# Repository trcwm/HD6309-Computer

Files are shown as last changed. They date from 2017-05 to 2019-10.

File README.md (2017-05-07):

# HD6309-Computer
A computer based on the HD6309 CPU, done for the Retro Challenge 2017/04.

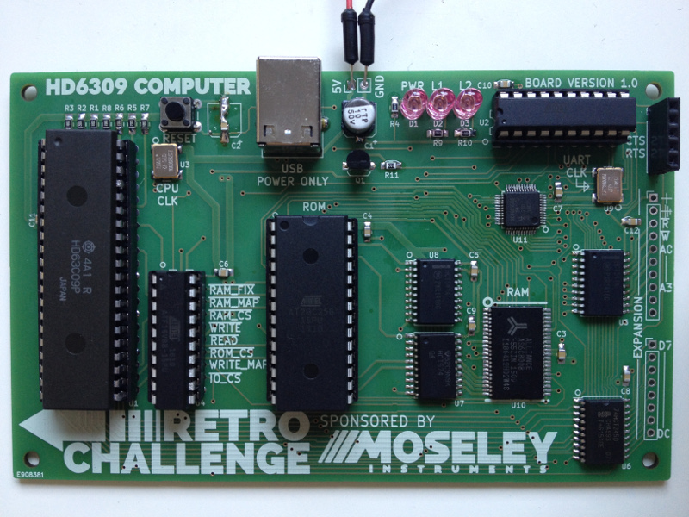
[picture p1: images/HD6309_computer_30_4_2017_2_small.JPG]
HD6309 Computer Image

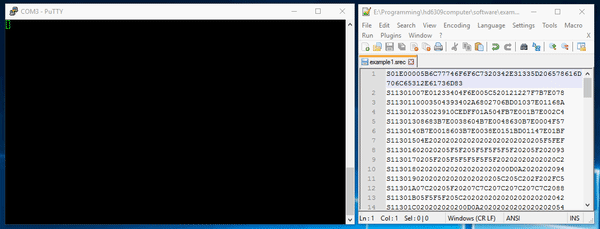
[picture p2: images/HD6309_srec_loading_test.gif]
HD6309 Computer Image


Read the blog: [https://namoseley.wordpress.com/category/retrochallenge/](https://namoseley.wordpress.com/category/retrochallenge/)

Features:
* HD6309 CPU
	* Binary compatible to MC6809
	* ..but faster instruction execution,
	* ..extended registers,
	* ..additional instructions,
	* and lots more!
* 1MB of RAM:
    * mapped in 32K pages at 0x0000 .. 0x7FFF
    * fixed page at 0x8000 .. 0xDFFF
* 2KB of IO space:
    * SC16C550B UART at 0xE000
    * 8-bit expansions port at 0xE010(untested!)
* Memory map register:
    * 5-bit entry sets A15..A19 on RAM
    * reg at address 0xE800
* 4KB of ROM:
    * Memory check
    * SREC loader

Licence: CERN Open Hardware Licence v1.2

Development time provided by: http://www.moseleyinstruments.com

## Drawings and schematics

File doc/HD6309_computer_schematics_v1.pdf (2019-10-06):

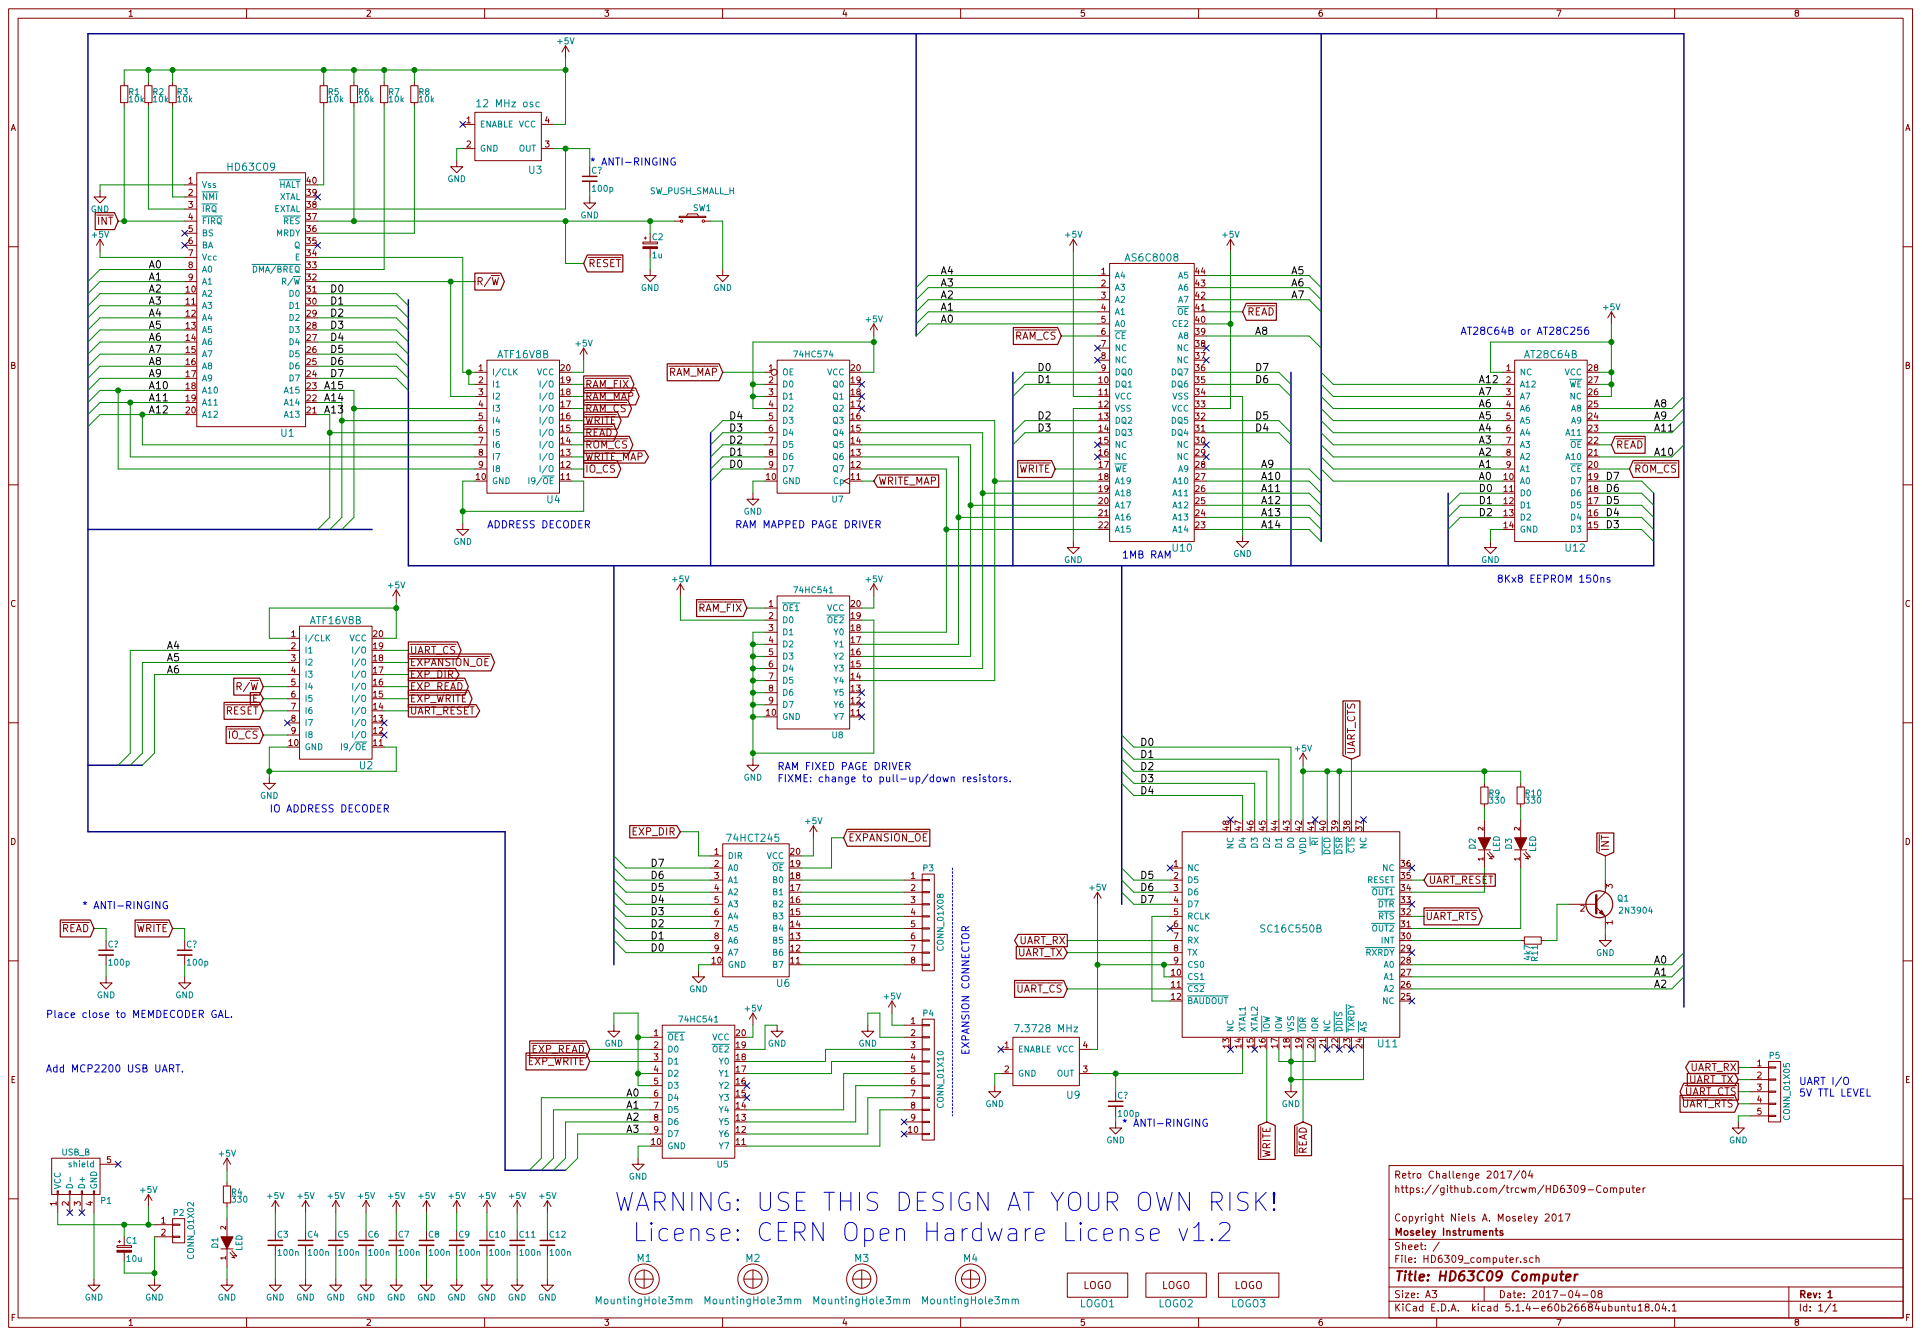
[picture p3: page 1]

I4 5
I5 6

5V TTL LEVEL RAM FIXED PAGE DRIVER
FIXME: change to pull-up/down resistors.

Place close to MEMDECODER GAL.

WARNING: USE THIS DESIGN AT YOUR OWN RISK!
License: CERN Open Hardware License v1.2

https://github.com/trcwm/HD6309-Computer

Copyright Niels A. Moseley 2017
File: HD6309_computer.sch Sheet: / Moseley Instruments

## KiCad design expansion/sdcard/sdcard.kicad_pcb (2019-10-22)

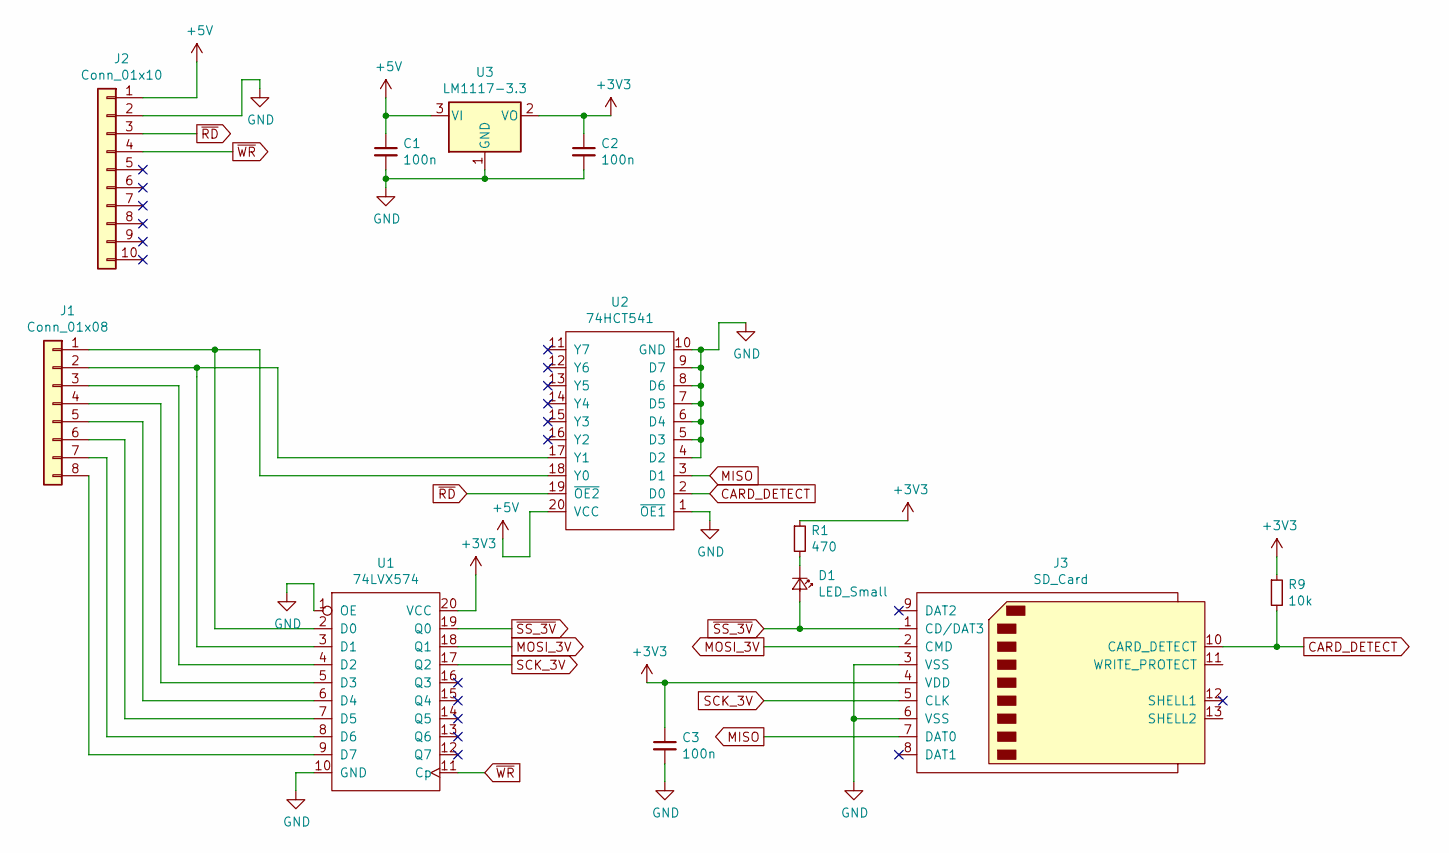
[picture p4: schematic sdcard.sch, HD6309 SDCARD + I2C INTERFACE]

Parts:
C1, C2, C3: 100n; C_0805_2012Metric_Pad1.15x1.40mm_HandSolder
D1: LED_Small; LED_0805_2012Metric_Pad1.15x1.40mm_HandSolder
J1: Conn_01x08; PinHeader_1x08_P2.54mm_Vertical
J2: Conn_01x10; PinHeader_1x10_P2.54mm_Vertical
J3: SD_Card; SD_TE_2041021
R1: 470; R_0805_2012Metric_Pad1.15x1.40mm_HandSolder
R9: 10k; R_0805_2012Metric_Pad1.15x1.40mm_HandSolder
U1: 74LVX574; SOIC-20W_7.5x12.8mm_P1.27mm
U2: 74HCT541; SOIC-20W_7.5x12.8mm_P1.27mm
U3: LM1117-3.3; SOT-223-3_TabPin2

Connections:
+3V3: C2.1, C3.1, J3.4 (VDD), R1.1, R9.1, U1.20 (VCC), U3.2 (VO)
+5V: C1.1, J2.1, U2.20 (VCC), U3.3 (VI)
CARD_DETECT: J3.10 (CARD_DETECT), R9.2, U2.2 (D0)
GND: C1.2, C2.2, C3.2, J2.2, J3.3 (VSS), J3.6 (VSS), U1.1 (OE), U1.10 (GND), U2.1 (~OE1), U2.4 (D2), U2.5 (D3), U2.6 (D4), U2.7 (D5), U2.8 (D6), U2.9 (D7), U2.10 (GND), U3.1 (GND)
MISO: J3.7 (DAT0), U2.3 (D1)
MOSI_3V: J3.2 (CMD), U1.18 (Q1)
unnamed: D1.1 (K), R1.2
unnamed: J1.1, U1.2 (D0), U2.18 (Y0)
unnamed: J1.2, U1.3 (D1), U2.17 (Y1)
unnamed: J1.3, U1.4 (D2)
unnamed: J1.4, U1.5 (D3)
unnamed: J1.5, U1.6 (D4)
unnamed: J1.6, U1.7 (D5)
unnamed: J1.7, U1.8 (D6)
unnamed: J1.8, U1.9 (D7)
SCK_3V: J3.5 (CLK), U1.17 (Q2)
~RD: J2.3, U2.19 (~OE2)
~SS_3V: D1.2 (A), J3.1 (CD/DAT3), U1.19 (Q0)
~WR: J2.4, U1.11 (Cp)

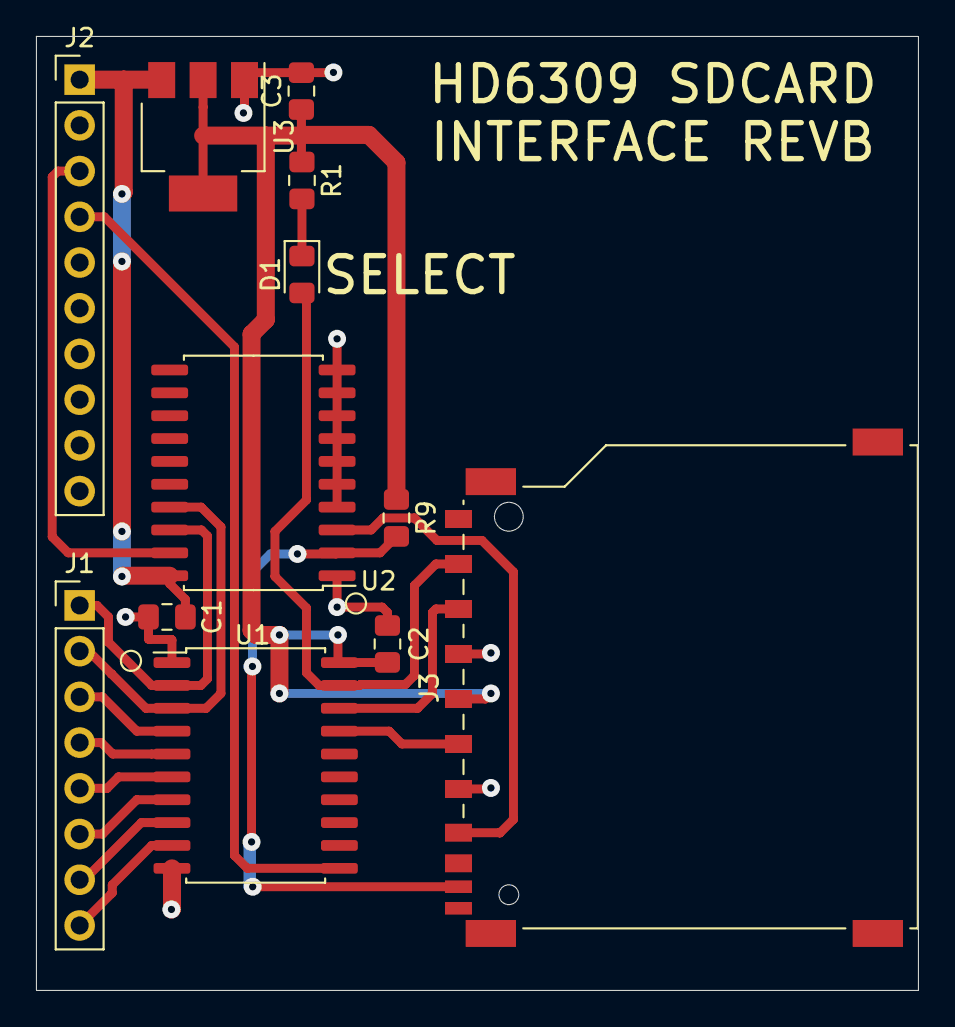
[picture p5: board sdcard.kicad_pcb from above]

Board: 2 copper layers, 49.0 x 53.0 mm, 12 parts (0 on the bottom side), 19 nets.

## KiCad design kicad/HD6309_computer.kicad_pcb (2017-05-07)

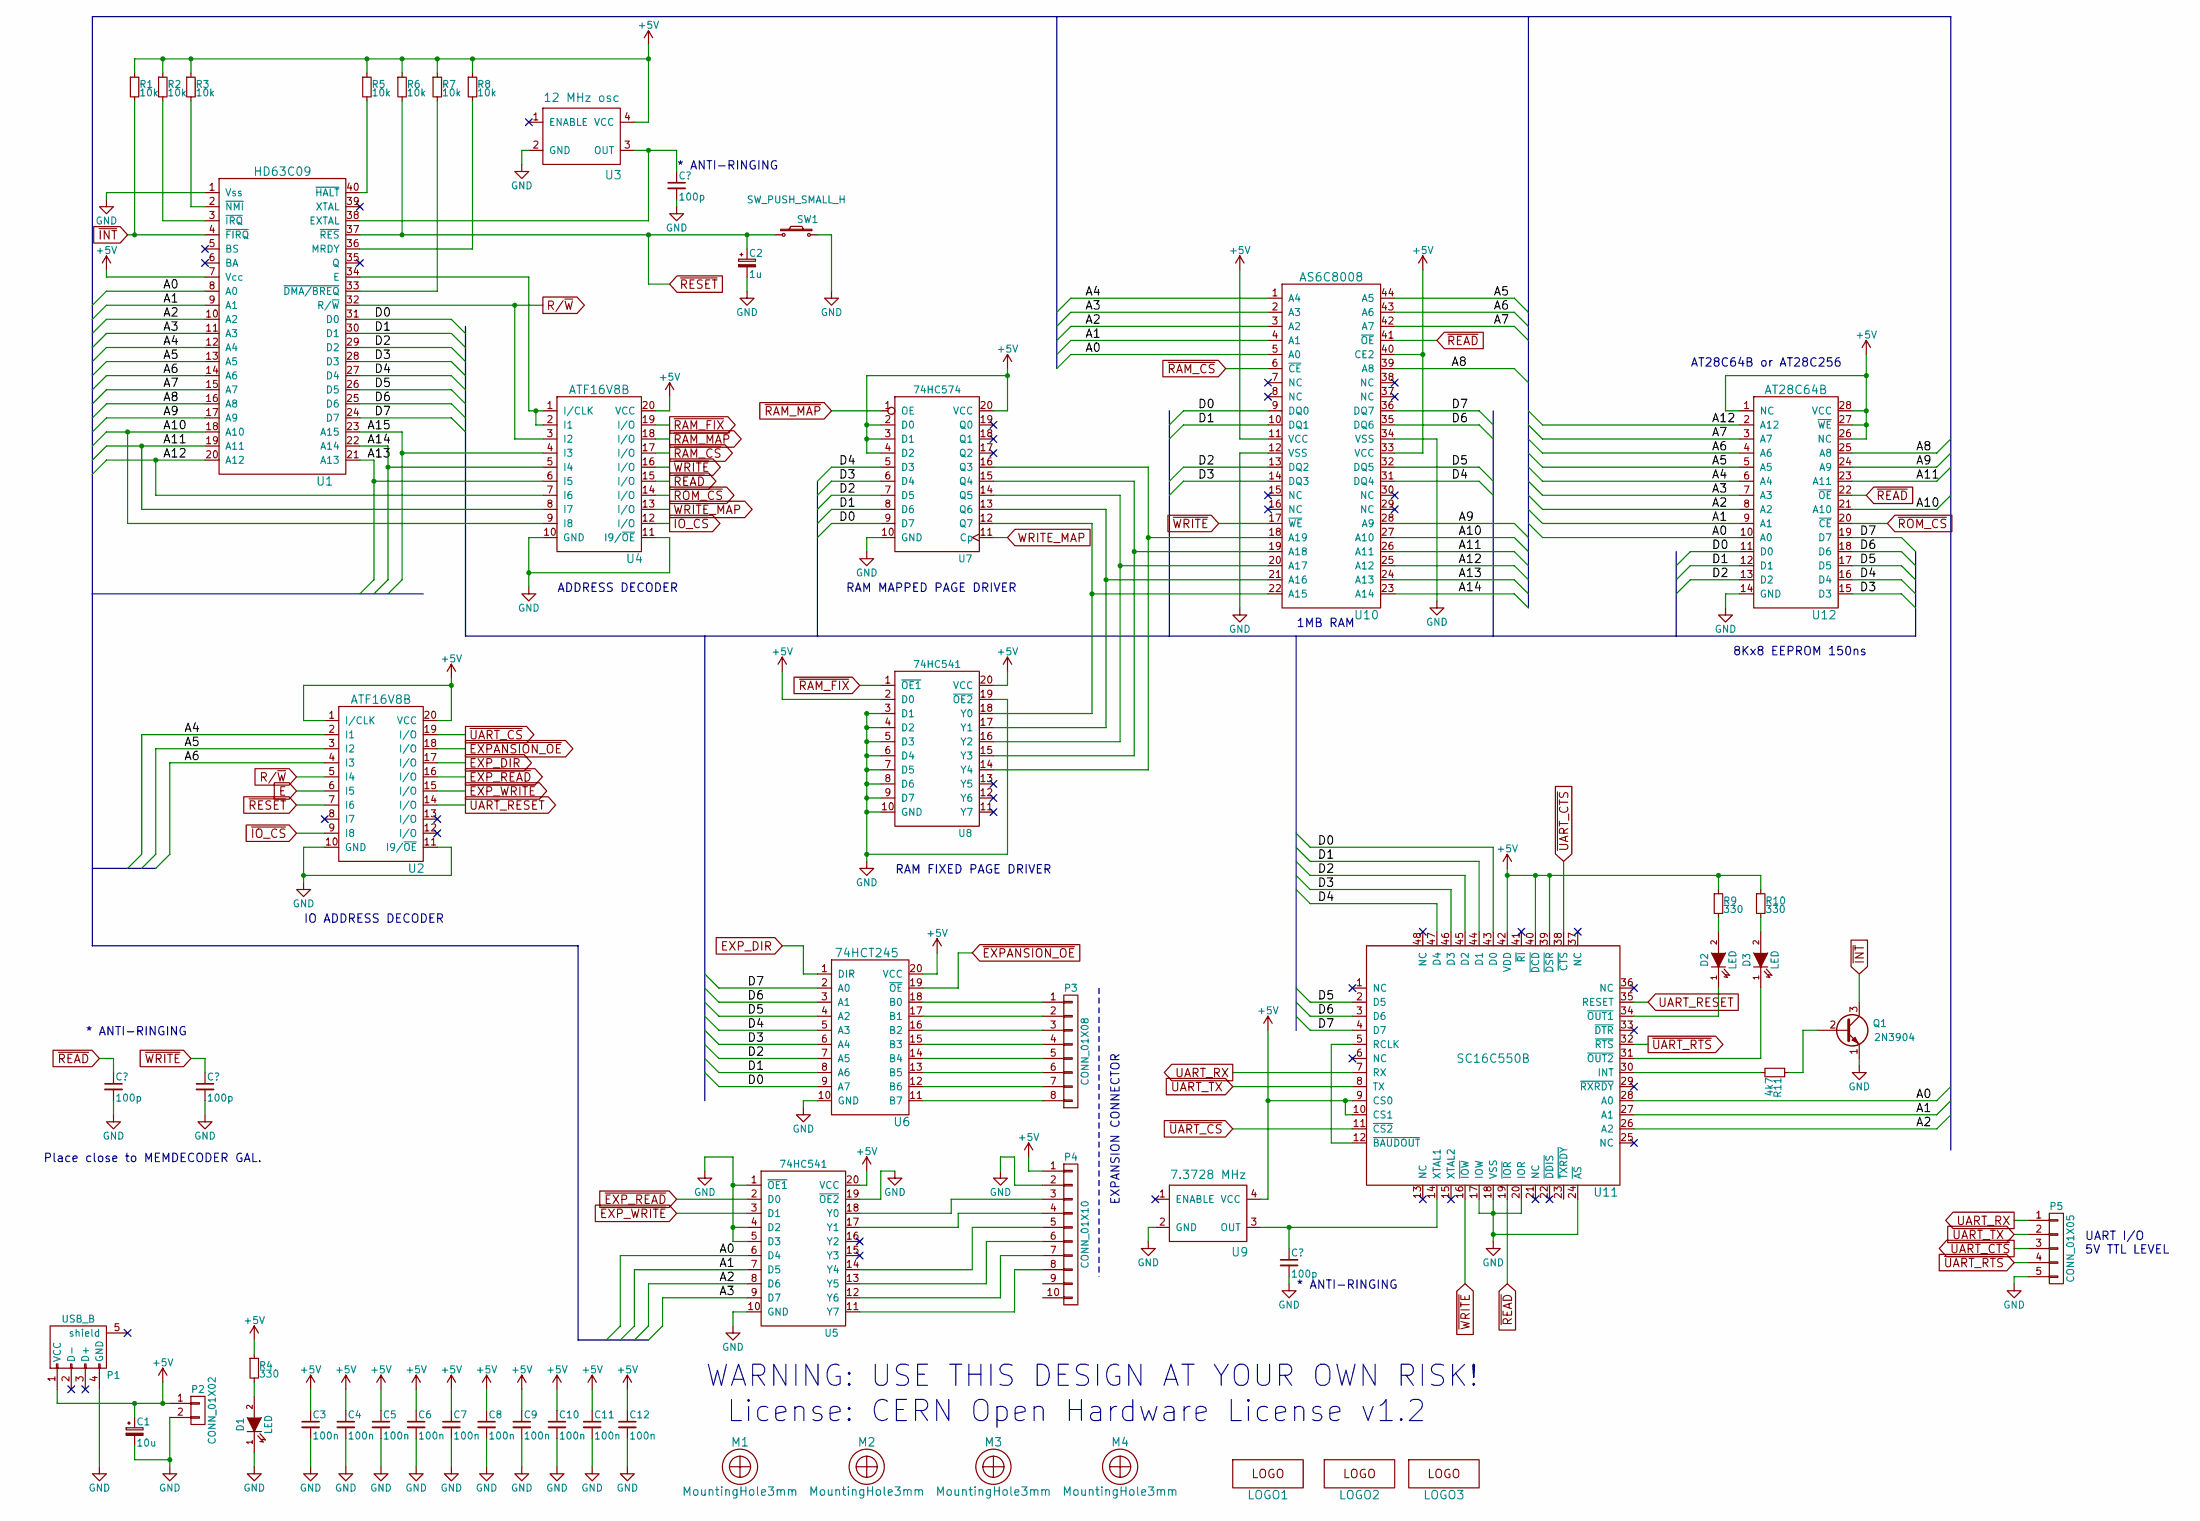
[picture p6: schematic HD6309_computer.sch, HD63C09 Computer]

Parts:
C1: 10u; CP_Elec_6.3x5.3
C2: 1u; CP_Elec_6.3x5.3
C3, C4, C5, C6, C7, C8, C9, C10, C11, C12: 100n; C_0805_HandSoldering
D1, D2, D3: LED; LED_D3.0mm_centered
LOGO1: Logo; moseley_instruments_logo_smaller
LOGO2: Logo; retro_challenge_logo
LOGO3: Logo; HD6309_computer_name
M1, M2, M3, M4: MountingHole3mm; MountingHole_3.2mm_M3_DIN965
P1: USB_B
P2: CONN_01X02; Pin_Header_Straight_1x02_Pitch2.54mm
P3: CONN_01X08; Pin_Header_Straight_1x08_Pitch2.54mm
P4: CONN_01X10; Pin_Header_Straight_1x10_Pitch2.54mm
P5: CONN_01X05; Pin_Header_Straight_1x05_Pitch2.54mm
Q1: 2N3904; TO-92_Inline_Wide
R1, R2, R3, R5, R6, R7, R8: 10k; R_0805_HandSoldering
R4, R9, R10: 330; R_0805_HandSoldering
R11: 4k7; R_0805_HandSoldering
SW1: SW_PUSH_SMALL_H; SW_PUSH_6mm
U1: HD63C09; DIP-40_W15.24mm_LongPads
U2, U4: ATF16V8B; DIP-20_W7.62mm_LongPads
U3: 12 MHz osc; OSCSMD7x5
U5, U8: 74HC541; SOIC-20W_7.5x12.8mm_Pitch1.27mm
U6: 74HCT245; SOIC-20W_7.5x12.8mm_Pitch1.27mm
U7: 74HC574; SOIC-20W_7.5x12.8mm_Pitch1.27mm
U9: 7.3728 MHz; OSCSMD7x5
U10: AS6C8008; TSOP-II_44pin_W400mil
U11: SC16C550B; LQFP-48_7x7mm_Pitch0.5mm
U12: AT28C64B; DIP-28_W15.24mm_LongPads

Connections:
/A0: U1.8 (A0), U5.6 (D4), U10.5 (A0), U11.28 (A0), U12.10 (A0)
/A1: U1.9 (A1), U5.7 (D5), U10.4 (A1), U11.27 (A1), U12.9 (A1)
/A2: U1.10 (A2), U5.8 (D6), U10.3 (A2), U11.26 (A2), U12.8 (A2)
/A3: U1.11 (A3), U5.9 (D7), U10.2 (A3), U12.7 (A3)
/A4: U1.12 (A4), U2.2 (I1), U10.1 (A4), U12.6 (A4)
/A5: U1.13 (A5), U2.3 (I2), U10.44 (A5), U12.5 (A5)
/A6: U1.14 (A6), U2.4 (I3), U10.43 (A6), U12.4 (A6)
/A7: U1.15 (A7), U10.42 (A7), U12.3 (A7)
/A8: U1.16 (A8), U10.39 (A8), U12.25 (A8)
/A9: U1.17 (A9), U10.28 (A9), U12.24 (A9)
/A10: U1.18 (A10), U4.9 (I8), U10.27 (A10), U12.21 (A10)
/A11: U1.19 (A11), U4.8 (I7), U10.26 (A11), U12.23 (A11)
/A12: U1.20 (A12), U4.7 (I6), U10.25 (A12), U12.2 (A12)
/A13: U1.21 (A13), U4.6 (I5), U10.24 (A13)
/A14: U1.22 (A14), U4.5 (I4), U10.23 (A14)
/A15: U1.23 (A15), U4.4 (I3)
/D0: U1.31 (D0), U6.9 (A7), U7.9 (D7), U10.9 (DQ0), U11.43 (D0), U12.11 (D0)
/D1: U1.30 (D1), U6.8 (A6), U7.8 (D6), U10.10 (DQ1), U11.44 (D1), U12.12 (D1)
/D2: U1.29 (D2), U6.7 (A5), U7.7 (D5), U10.13 (DQ2), U11.45 (D2), U12.13 (D2)
/D3: U1.28 (D3), U6.6 (A4), U7.6 (D4), U10.14 (DQ3), U11.46 (D3), U12.15 (D3)
/D4: U1.27 (D4), U6.5 (A3), U7.5 (D3), U10.31 (DQ4), U11.47 (D4), U12.16 (D4)
/D5: U1.26 (D5), U6.4 (A2), U10.32 (DQ5), U11.2 (D5), U12.17 (D5)
/D6: U1.25 (D6), U6.3 (A1), U10.35 (DQ6), U11.3 (D6), U12.18 (D6)
/D7: U1.24 (D7), U6.2 (A0), U10.36 (DQ7), U11.4 (D7), U12.19 (D7)
EXP_DIR: U2.17 (I/O), U6.1 (DIR)
unnamed: D1.2 (A), R4.2
unnamed: D2.1 (K), U11.34 (~OUT1)
unnamed: D2.2 (A), R9.2
unnamed: D3.1 (K), U11.31 (~OUT2)
unnamed: D3.2 (A), R10.2
unnamed: P3.1, U6.18 (B0)
unnamed: P3.2, U6.17 (B1)
unnamed: P3.3, U6.16 (B2)
unnamed: P3.4, U6.15 (B3)
unnamed: P3.5, U6.14 (B4)
unnamed: P3.6, U6.13 (B5)
unnamed: P3.7, U6.12 (B6)
unnamed: P3.8, U6.11 (B7)
unnamed: P4.3, U5.18 (Y0)
unnamed: P4.4, U5.17 (Y1)
unnamed: P4.5, U5.14 (Y4)
unnamed: P4.6, U5.13 (Y5)
unnamed: P4.7, U5.12 (Y6)
unnamed: P4.8, U5.11 (Y7)
unnamed: Q1.2 (B), R11.1
unnamed: R2.2, U1.3 (~IRQ)
unnamed: R3.2, U1.2 (~NMI)
unnamed: R5.2, U1.40 (~HALT)
unnamed: R7.2, U1.33 (~DMA/BREQ)
unnamed: R8.2, U1.36 (MRDY)
unnamed: R11.2, U11.30 (INT)
unnamed: U1.34 (E), U4.1 (I/CLK), U4.2 (I1)
unnamed: U1.38 (EXTAL), U3.3 (OUT)
unnamed: U7.16 (Q3), U8.14 (Y4), U10.18 (A19)
unnamed: U7.15 (Q4), U8.15 (Y3), U10.19 (A18)
unnamed: U7.14 (Q5), U8.16 (Y2), U10.20 (A17)
unnamed: U7.13 (Q6), U8.17 (Y1), U10.21 (A16)
unnamed: U7.12 (Q7), U8.18 (Y0), U10.22 (A15)
unnamed: U11.5 (RCLK), U11.12 (~BAUDOUT)
unnamed: U9.3 (OUT), U11.14 (XTAL1)
R/~W: U1.32 (R/~W), U2.5 (I4), U4.3 (I2)
UART_RX: P5.1, U11.7 (RX)
UART_TX: P5.2, U11.8 (TX)
WRITE_MAP: U4.13 (I/O), U7.11 (Cp)
~EXPANSION_OE: U2.18 (I/O), U6.19 (~OE)
~EXP_READ: U2.16 (I/O), U5.2 (D0)
~EXP_WRITE: U2.15 (I/O), U5.3 (D1)
~INT: Q1.3 (C), R1.2, U1.4 (~FIRQ)
~IO_CS: U2.9 (I8), U4.12 (I/O)
~RAM_CS: U4.17 (I/O), U10.6 (~CE)
~RAM_FIX: U4.19 (I/O), U8.1 (~OE1)
~RAM_MAP: U4.18 (I/O), U7.1 (OE)
~READ: U4.15 (I/O), U10.41 (~OE), U11.19 (~IOR), U12.22 (~OE)
~ROM_CS: U4.14 (I/O), U12.20 (~CE)
~UART_CS: U2.19 (I/O), U11.11 (~CS2)
~UART_CTS: P5.3, U11.38 (~CTS)
~UART_RTS: P5.4, U11.32 (~RTS)
~WRITE: U4.16 (I/O), U10.17 (~WE), U11.16 (~IOW)

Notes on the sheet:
IO ADDRESS DECODER
RAM FIXED PAGE DRIVER
RAM MAPPED PAGE DRIVER
ADDRESS DECODER
1MB RAM
8Kx8 EEPROM 150ns
UART I/O 5V TTL LEVEL
EXPANSION CONNECTOR
* ANTI-RINGING
Place close to MEMDECODER GAL.
AT28C64B or AT28C256
License: CERN Open Hardware License v1.2
WARNING: USE THIS DESIGN AT YOUR OWN RISK!

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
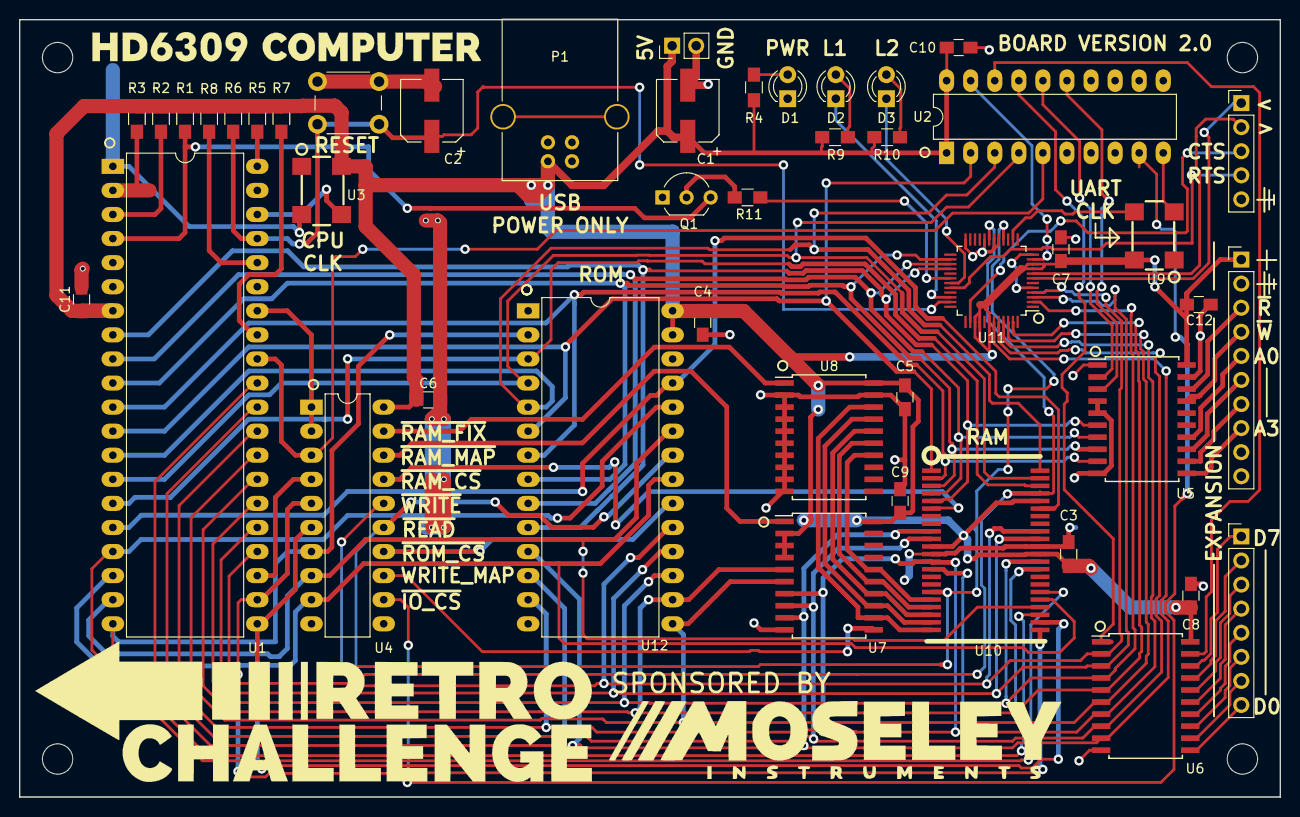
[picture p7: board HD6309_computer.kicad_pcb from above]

Board: 2 copper layers, 133.0 x 82.0 mm, 52 parts (0 on the bottom side), 81 nets.

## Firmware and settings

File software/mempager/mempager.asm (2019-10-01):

;
; Test for the paging mechanism of the HD6309 computer
;
; Niels A. Moseley
; www.moseleyinstruments.com
;

; ==================================================
; SYSTEM CONSTANTS
; ==================================================

RAMSTART  EQU $0000
RAMEND    EQU $E000
STACK     EQU $DFE0

PAGEREG   EQU $E800

; ==================================================
; UART ADDRESSES
; ==================================================
SER_TX     EQU $E000
SER_RX     EQU $E000
SER_IER    EQU $E001
SER_FCR    EQU $E002
SER_ISR    EQU $E002
SER_LCR    EQU $E003
SER_MCR    EQU $E004
SER_LSR    EQU $E005
SER_MSR    EQU $E006
SER_SPR    EQU $E007
SER_DLL    EQU $E000
SER_DLM    EQU $E001

; run program in non-paged part of memory!
    ORG $8000
    
    JMP __START

; ==================================================
; OUTPUT A CHARACTER TO THE CONSOLE
; BLOCKS ON UART TX FULL
; ==================================================
OUTCHAR:
    PSHS B
OUTCHAR_1:
    LDB SER_LSR
    BITB #32
    NOP
    NOP
    BEQ OUTCHAR_1
    STA SER_TX
    PULS B
    RTS    

; ==================================================
; GET A CHARACTER FROM THE CONSOLE
; BLOCKS ON UART RX EMPTY
; ==================================================    

INCHAR:
    PSHS B
INCHAR_1:
    LDB SER_LSR
    BITB #1
    NOP
    NOP    
    BEQ INCHAR_1
    LDA SER_RX
    PULS B
    RTS    
    
; ==================================================
; PRINT STRING POINTED TO BY X
; BLOCKS ON UART TX FULL
; ==================================================     
PRINTSTRING:
    PSHS A
PRINTSTRING_1:
    LDA ,X+
    BEQ PS_END
    JSR OUTCHAR
    JMP PRINTSTRING_1
PS_END:
    PULS A
    RTS     

; ==================================================
; WRITE 'A' REGISTER AS HEX TO UART
; BLOCKS ON UART TX FULL
; ==================================================        
PRINTAHEX:
    PSHS A
    PSHS A
    ; convert MS nibble
    LSRA
    LSRA
    LSRA
    LSRA
    CMPA #9
    BLS PRINTAHEX_1
    ADDA #7             ; 'A'-'9'-1 : 65 - 57 - 1 = 7
PRINTAHEX_1:
    ADDA #'0'
    JSR OUTCHAR
    ; convert LS nibble
    PULS A
    ANDA #$0F
    CMPA #9
    BLS PRINTAHEX_2
    ADDA #7
PRINTAHEX_2:
    ADDA #'0'
    JSR OUTCHAR
    PULS A
    RTS
    
; ==================================================
; START OF PROGRAM
; ==================================================
    
__START:    
    LDS #STACK
    ORCC #%01010000 ; disable interrupts
    
    LDA #$00
    STA PAGEREG
    
    ; ****************************************
    ; init UART 
    ;   baud divisor to 48 -> 9600 baud
    ;   8 bits, 1 stop bit, no parity
    ; 
    ; ****************************************
    CLRA 
    STA SER_IER     ; no interrupts

    STA SER_FCR     ; no FIFO
  
    LDA #$83        ; 8 bits per symbol, no parity, enable baud reg access
    STA SER_LCR     ;   line control
 
    LDA #$4         ; set at least one led to ON
    STA SER_MCR     ;   modem control
   
    LDA #48
    STA SER_DLL
   
    CLRA
    STA SER_DLM
 
    LDA #$03        ; 8 bits per symbol, no parity, disable baud reg access
    STA SER_LCR
    
    ; ==================================================
    ; Write + read to page 2
    ; ==================================================
    ; set page register
    LDA #$02
    STA PAGEREG

    LDX #TEXT1
    JSR PRINTSTRING
    
    LDA #$FF
    STA $0000
    LDX #WRITETEXT
    JSR PRINTSTRING
    JSR PRINTAHEX
    LDX #EOLSTR
    JSR PRINTSTRING
    
    LDA $0000
    LDX #READTEXT
    JSR PRINTSTRING
    JSR PRINTAHEX    
    LDX #EOLSTR    
    JSR PRINTSTRING
    CMPA #$FF
    BNE PAGE_ERROR    

    ; ==================================================
    ; Write + read to page 0
    ; ==================================================    
    ; set page register
    LDA #$00
    STA PAGEREG

    LDX #TEXT0
    JSR PRINTSTRING
    
    LDA #$AA
    STA $0000
    LDX #WRITETEXT
    JSR PRINTSTRING
    JSR PRINTAHEX
    LDX #EOLSTR
    JSR PRINTSTRING    
    
    LDA $0000
    LDX #READTEXT
    JSR PRINTSTRING
    JSR PRINTAHEX
    LDX #EOLSTR
    JSR PRINTSTRING     
    CMPA #$AA
    BNE PAGE_ERROR
   
    
    ; ==================================================
    ; Read again from page 2
    ; ==================================================    
    ; set page register
    LDA #$02
    STA PAGEREG

    LDX #TEXT1
    JSR PRINTSTRING
    
    LDA $0000
    LDX #READTEXT
    JSR PRINTSTRING
    JSR PRINTAHEX
    CMPA #$FF
    BNE PAGE_ERROR    
    LDX #EOLSTR
    JSR PRINTSTRING
    JMP MEMTEST
    
PAGE_ERROR:
    LDX #PAGEERRORSTR
    JSR PRINTSTRING
    JMP QUIT    
    
    ; ==================================================
    ; Perform exhaustive memory test
    ; ================================================== 
MEMTEST:    
    CLRB        ; page ID
    
NEXTPAGE:
    CMPB #1     ; don't check page 1 because
                ; that's where the program is running!
    BEQ SKIPPAGE
    CMPB #32    ; no more than 32 pages!
    BHS DONE
    STB PAGEREG
    LDX #CHECKSTR
    JSR PRINTSTRING
    TFR B,A
    JSR PRINTAHEX
    LDA #13
    JSR OUTCHAR
    
    LDX #$0000    
NEXTBYTE:
    LDA #$AA
    STA ,X
    LDA ,X
    CMPA #$AA
    BNE MEM_ERROR
    LDA #$55
    STA ,X
    LDA ,X+
    CMPA #$55
    BNE MEM_ERROR    
    CMPX #$8000
    BNE NEXTBYTE
SKIPPAGE:
    INCB
    JMP NEXTPAGE
    
DONE:
    LDX #DONESTR
    JSR PRINTSTRING
    JMP QUIT
        
MEM_ERROR:
    LDX #MEMERRORSTR
    JSR PRINTSTRING
    JMP QUIT
    
; ==================================================
; Program end
; ==================================================     
    
QUIT:
    JMP QUIT

; ==================================================
; Strings
; ==================================================         
    
TEXT0:    
    .ascii "Page register set to 0."
    .db 13,10,0    
    
TEXT1:    
    .ascii "Page register set to 2."
    .db 13,10,0

PAGEERRORSTR:
    .ascii "Paging error!"
    .db 13,10,0

MEMERRORSTR:
    .ascii "Memory error!"
    .db 13,10,0

CHECKSTR:
    .asciz "Checking page $"
    
DONESTR:
    .ascii "Done: memory ok!"
    .db 13,10,0
    
READTEXT:
    .asciz "Data read as: $"

WRITETEXT:
    .asciz "Data written: $"

EOLSTR:
    .db 13,10,0
    

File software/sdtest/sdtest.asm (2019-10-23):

; HD6309 Computer SD card expansion test
;
; Retro Challenge 2019/10
; Niels A. Moseley
; www.moseleyinstruments.com
;
; INPORT:
;   bit 7: /CARD_DETECT
;   bit 6: MISO
;
; OUTPORT:
;   bit 7: /SS
;   bit 6: MOSI
;   bit 5: SCK
;
; default state for the MOSI line is '1'
;
; https://electronics.stackexchange.com/questions/77417/what-is-the-correct-command-sequence-for-microsd-card-initialization-in-spi

; ==================================================
; SYSTEM CONSTANTS
; ==================================================

RAMSTART  EQU $0000
RAMEND    EQU $E000
STACK     EQU $DFE0

PAGEREG   EQU $E800
IOPORT    EQU $E010

; ==================================================
; UART ADDRESSES
; ==================================================
SER_TX     EQU $E000
SER_RX     EQU $E000
SER_IER    EQU $E001
SER_FCR    EQU $E002
SER_ISR    EQU $E002
SER_LCR    EQU $E003
SER_MCR    EQU $E004
SER_LSR    EQU $E005
SER_MSR    EQU $E006
SER_SPR    EQU $E007
SER_DLL    EQU $E000
SER_DLM    EQU $E001

    ORG $0000
    
    JMP START

; ==================================================
; OUTPUT A CHARACTER TO THE CONSOLE
; BLOCKS ON UART TX FULL
; ==================================================
OUTCHAR:
    PSHS B
OUTCHAR_1:
    LDB SER_LSR
    BITB #32
    NOP
    NOP
    BEQ OUTCHAR_1
    STA SER_TX
    PULS B
    RTS    

; ==================================================
; GET A CHARACTER FROM THE CONSOLE
; BLOCKS ON UART RX EMPTY
; ==================================================    

INCHAR:
    PSHS B
INCHAR_1:
    LDB SER_LSR
    BITB #1
    NOP
    NOP    
    BEQ INCHAR_1
    LDA SER_RX
    PULS B
    RTS    
    
; ==================================================
; PRINT STRING POINTED TO BY X
; BLOCKS ON UART TX FULL
; ==================================================     
PRINTSTRING:
    PSHS A
PRINTSTRING_1:
    LDA ,X+
    BEQ PS_END
    JSR OUTCHAR
    JMP PRINTSTRING_1
PS_END:
    PULS A
    RTS     

; ==================================================
; WRITE 'A' REGISTER AS HEX TO UART
; BLOCKS ON UART TX FULL
; ==================================================        
PRINTAHEX:
    PSHS A
    PSHS A
    ; convert MS nibble
    LSRA
    LSRA
    LSRA
    LSRA
    CMPA #9
    BLS PRINTAHEX_1
    ADDA #7             ; 'A'-'9'-1 : 65 - 57 - 1 = 7
PRINTAHEX_1:
    ADDA #'0'
    JSR OUTCHAR
    ; convert LS nibble
    PULS A
    ANDA #$0F
    CMPA #9
    BLS PRINTAHEX_2
    ADDA #7
PRINTAHEX_2:
    ADDA #'0'
    JSR OUTCHAR
    PULS A
    RTS


; ==================================================
;   SPI INTERFACE - delay for a bit
; ==================================================

; SHOULD BE IN RAM!
SPI_OUT   .db 0   ; SPI output shadow register
SPI_SPEED .db 255

SPI_DELAY:
    PSHS A
    LDA SPI_SPEED
SPI_DELAY1:  
    DECA
    BNE SPI_DELAY1
    PULS A
    RTS

; ==================================================
;   SPI INTERFACE - 
; ==================================================

SCK1:
    PSHS A
    LDA SPI_OUT
    ORA #32
    STA SPI_OUT
    STA IOPORT
    PULS A
    RTS

SCK0:
    PSHS A
    LDA SPI_OUT
    ANDA #$DF
    STA SPI_OUT
    STA IOPORT
    PULS A
    RTS

NSS1:
    PSHS A
    LDA SPI_OUT
    ORA #128
    STA SPI_OUT
    STA IOPORT
    PULS A
    RTS

NSS0:
    PSHS A
    LDA SPI_OUT
    ANDA #$7F
    STA SPI_OUT
    STA IOPORT
    PULS A
    RTS

MOSI1:
    PSHS A
    LDA SPI_OUT
    ORA #64
    STA SPI_OUT
    STA IOPORT
    PULS A
    RTS

MOSI0:
    PSHS A
    LDA SPI_OUT
    ANDA #$B5
    STA SPI_OUT
    STA IOPORT
    PULS A
    RTS

; SEND 'A' register, MSB first
SPI_TXA:
    PSHS B
    LDB #8
SPI_TX_NEXTBIT:    
    TSTA
    ; set the MOSI state
    BPL SPI_TXA0  ; is MSB of A is 0 -> branch
    BSR MOSI1
    BRA SPI_TXA1
SPI_TXA0:
    BSR MOSI0
SPI_TXA1:
    ; toggle the SCK line
    BSR SCK1
    BSR SPI_DELAY
    BSR SCK0
    BSR SPI_DELAY
    ASLA
    DECB
    BNE SPI_TX_NEXTBIT
    PULS B
    RTS

; READ MISO into 'A' register
SPI_RXA:
    PSHS B
    LDB #8
    BSR MOSI1     ; default state when RXing
SPI_RX_NEXT_BIT:
    BSR SCK1
    JSR SPI_DELAY
    ; read MISO bit
    PSHS B
    LDB IOPORT
    ASLB 
    ASLB          ; shift MISO bit into the carry flag
    ROLA          ; into A register
    PULS B

    BSR SCK0
    JSR SPI_DELAY

    DECB
    BNE SPI_RX_NEXT_BIT
    PULS B
    RTS

; ==================================================
; SEND SDCARD COMMAND POINTED TO BY X REG
;   assumed that NSS is 1
;   sets NSS to 0
; ==================================================
SDTXCMD:
    LDA #$FF      ; send 8 idle clocks
    JSR SPI_TXA
    
    JSR NSS0
    
    LDA #$FF      ; send 8 idle clocks
    JSR SPI_TXA

    
    LDA ,X+       ; cmd byte
    JSR SPI_TXA
    LDA ,X+       ; payload byte 1
    JSR SPI_TXA
    LDA ,X+       ; payload byte 2
    JSR SPI_TXA
    LDA ,X+       ; payload byte 3
    JSR SPI_TXA 
    LDA ,X+       ; payload byte 4
    JSR SPI_TXA
    LDA ,X
    JSR SPI_TXA   ; checksum + stop bit

    ; turn-around time
    LDA #$FF
    JSR SPI_TXA

    RTS

; ==================================================
; READ SDCARD 1 BYTE RESPONSE INTO MEM -> X PTR
;   assumed that NSS is 0
;   saves X
; ==================================================
SDRX1:
    JSR SPI_RXA
    TSTA
    BMI SDRX1       ; MSB should be 0
    STA ,X
    RTS

; ==================================================
; READ SDCARD 4 BYTE RESPONSE INTO MEM -> X PTR
;   assumed that NSS is 0
;   saves X
; ==================================================
SDRX5:
    JSR SPI_RXA
    TSTA
    BMI SDRX5       ; MSB should be 0
    STA 0,X
    JSR SPI_RXA
    STA 1,X
    JSR SPI_RXA
    STA 2,X
    JSR SPI_RXA
    STA 3,X
    JSR SPI_RXA
    STA 4,X    
    RTS

; ==================================================
;   SD CARD INIT 
; ==================================================

; can be in ROM:
CMD0:   .db $40,0,0,0,0,$95
CMD8:   .db $48,0,0,1,$AA,$87
CMD41:  .db $69,0x40,0,0,0,1
CMD55:  .db $77,0,0,0,0,1
CMD58:  .db $7A,0,0,0,0,1

; SDRESP must be in RAM!
SDRESP:  .db 0,0,0,0,0

SDFAIL:
    LDX #SDERR
    JSR PRINTSTRING
    LDX #ASK    
    JSR PRINTSTRING
    JSR INCHAR      ; wait for key press
    ; intentional fall-through
    
    ; === INIT ENTRY POINT ===
SDINIT:
    LDA #255
    STA SPI_SPEED   ; set slowest speed
    JSR NSS1        ; deselect card
    JSR MOSI1       ; default state for MOSI
    JSR SCK0        ; default state for SCK
    LDB #10         ; 10 bytes -> spec says at least 74 clock cycles
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

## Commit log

2017-05-07 HD6309 computer - first public commit.
    [HD6309_computer.dsn, HD6309_computer.kicad_pcb, HD6309_computer.sch]
2019-09-30 Updated schematic with DRC fixes and TODOs
    [HD6309_computer.sch]
2019-10-06 Added v1 schematics as PDF for easier viewing
2019-10-06 Fixed IO decoder GAL?
    [HD6309_computer.sch]
2019-10-06 Added Kicad rescue libraries
    [HD6309_computer.sch]
2019-10-07 HD6309 SDCARD expansion.
    [sdcard.kicad_pcb, sdcard.sch]
2019-10-11 SDCard expansion updated.
    [sdcard.kicad_pcb, sdcard.sch]
